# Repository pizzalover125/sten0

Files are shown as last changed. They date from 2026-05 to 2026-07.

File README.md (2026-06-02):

# sten0
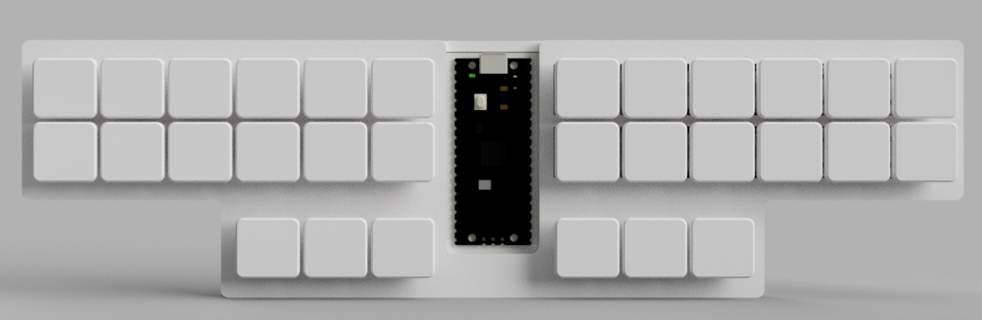
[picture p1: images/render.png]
render


sten0 is a minimalist stenography keyboard. it was meant to defeat the industry standard Uni v4 which is overpriced and unsymmetrical. it uses a 2-layer PCB and KMK firmware that converts to stenography with the industry-standard Plover firmware. 

### what is steno?
traditional stenography keyboards are keyboards used by transcribers in a courtroom to type extremely fast. hobbyists and now companies have created their own versions of steno keyboards. one can easily get 200 wpm using steno, demonstrated in the video here: https://www.youtube.com/watch?v=l8SWkR5y774. 

steno works by pressing multiple keys at once to create "chords" which create words. each key is associated with a specific sound. for example, to write "cat" press "K A T" all at once.

the company, stenokeyboards.com, is the leader of the steno industry with products that are pretty cool, but extremely expensive. worst of all, they are closed source. i wanted to make something better for cheaper.

### PCB + Schematic
I used KiCad 10.0 for the PCB design. The silkscreen art was created using https://www.fontspace.com/ and inputted to KiCad using the built-in Image Convertor tool.

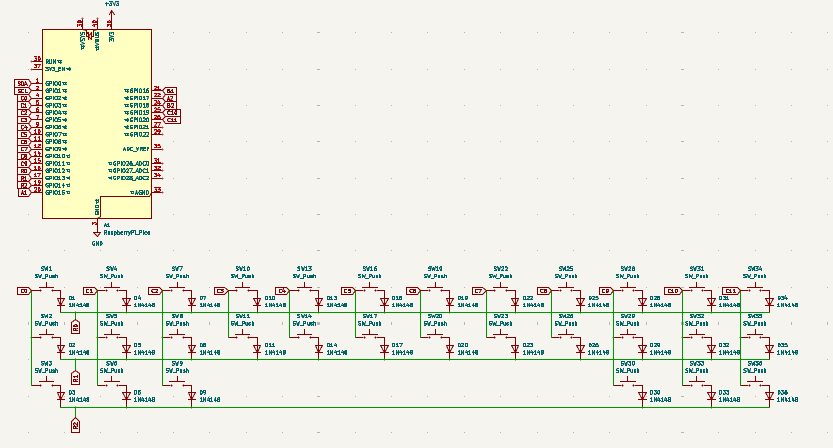
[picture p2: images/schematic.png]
schematic

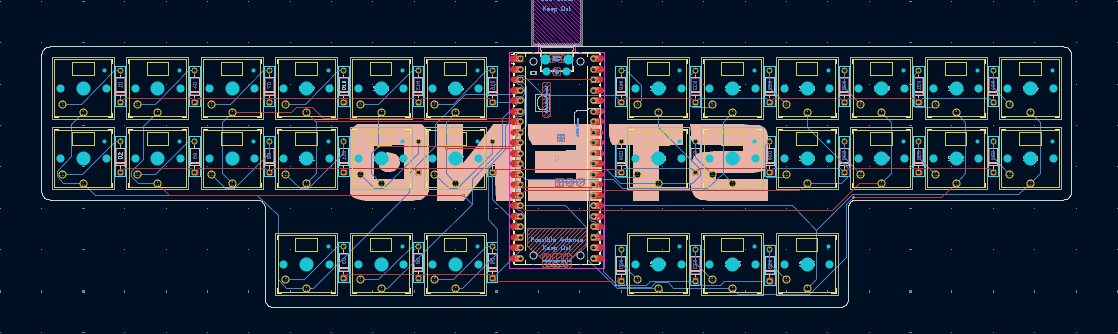
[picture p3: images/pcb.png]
pcb

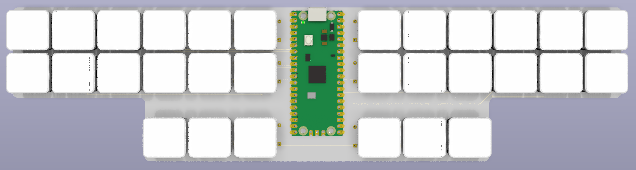
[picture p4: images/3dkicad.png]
3dkicad


### CAD
I used Onshape for the entire CAD. It features a front plate and a back plate. It is only 255.4 mm wide at its widest point, making it printable on a standard Bambu Lab A1 or any Bambu Lab 3d printer. Can be viewed here! https://cad.onshape.com/documents/f60da929d98268854f5791b9/w/b980d7f138533dbdb870e5ad/e/3b5277e683bbd7090a7e44ca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

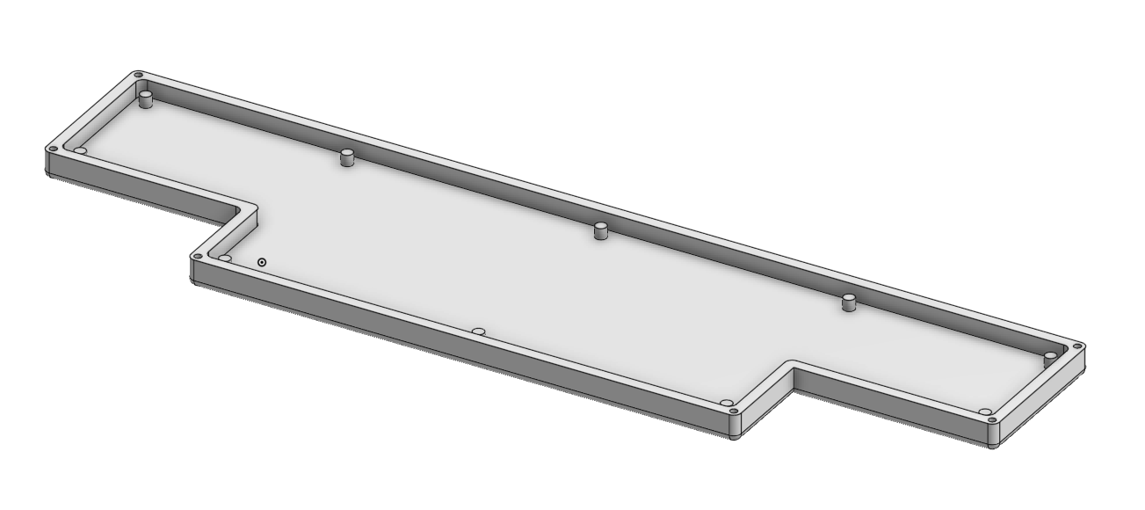
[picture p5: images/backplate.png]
back-plate

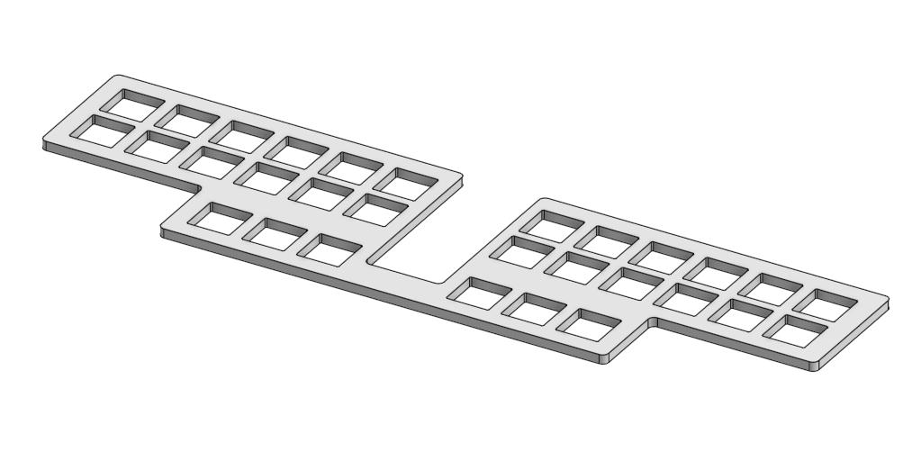
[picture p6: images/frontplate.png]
front-plate

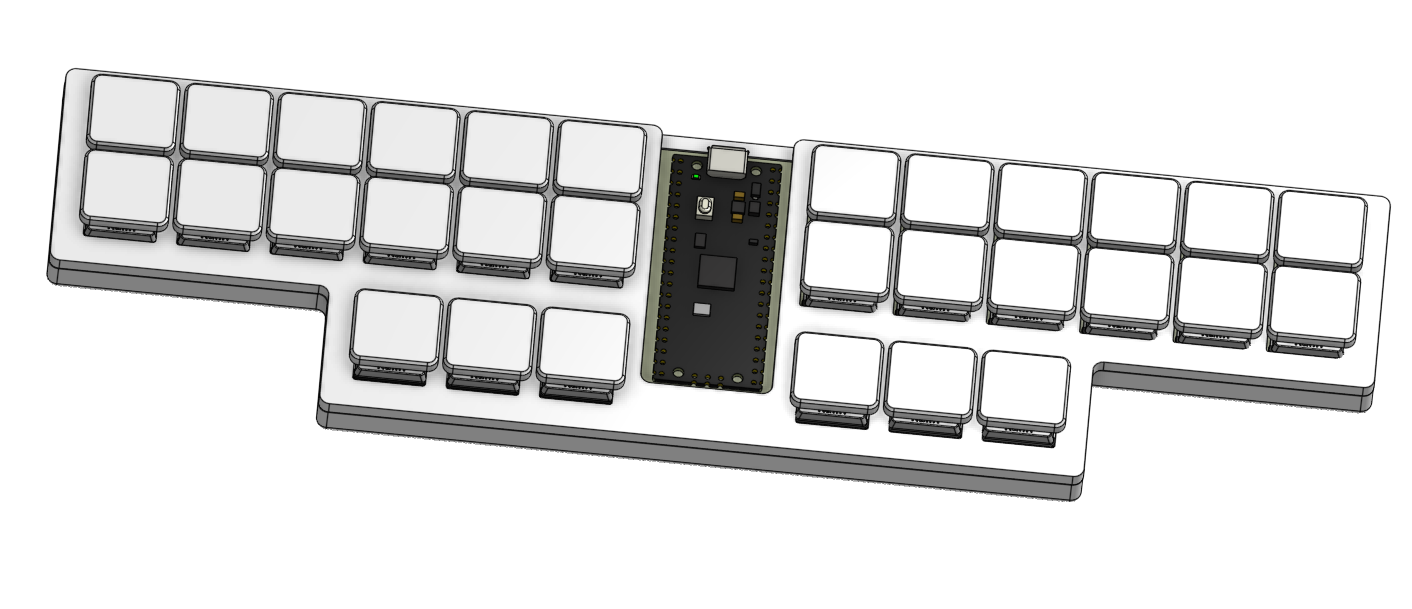
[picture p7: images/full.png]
full


### Firmware
The keyboard uses KMK. There is a standard keyboard matrix that links to standard QWERTY layout which will be converted to Steno layout with Plover firmware.

### Layout
This is the layout for both QWERTY and STENO. The blank keys are macro keys, meaning they can be mapped to anything!



### BOM
A detailed Bill of Materials can be found at https://docs.google.com/spreadsheets/d/1TjUF5DwXCz-duM485mYQtrJNJa8_saizqugbLS9kPO8/edit?gid=0#gid=0!

### Credits
Big thanks to Hack Club for funding the project + providing a LOT of help!

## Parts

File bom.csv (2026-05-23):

Item | Price | Link | Orders |  | Notes
2x RPi Pico Clones | 10.99 | https://www.amazon.com/gp/product/B0DKNKLMXP/ref=ox_sc_act_title_1?smid=A23J2M209QYJMZ&psc=1 | Amazon | 53.00 | The BOM on right is w/o taxes + shipping
70x Choc v1 Brown Switches | 36.89 | https://www.amazon.com/gp/product/B0F9WNSX15/ref=ewc_pr_img_2?smid=A6078EBK4K8X5&th=1 | JLCPCB | 21.08 | The Orders on left is w/ taxes and shipping
100x 1N4148 Diodes | 4.39 | https://www.amazon.com/gp/product/B081JKJM6N/ref=ewc_pr_img_3?smid=AMND9J0IFY6ZR&psc=1 |  |  | Using cheapest shipping on JLC
5x JLC PCB | 2.00 | https://www.amazon.com/gp/product/B081JKJM6N/ref=ewc_pr_img_3?smid=AMND9J0IFY6ZR&psc=1 | Total | 74.08 | Prime shipping on Amazon to make shipping free
4x M2x9 screws | 0.00 | Closet

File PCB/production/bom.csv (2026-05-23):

Designator | Footprint | Quantity | Value | LCSC Part #
A1 | RaspberryPi_Pico_Common_Unspecified | 1 | RaspberryPi_Pico
D1, D10, D11, D13, D14, D16, D17, D19, D2, D20, D22, D23, D25, D26, D28, D29, D3, D30, D31, D32, D33, D34, D35, D36, D4, D5, D6, D7, D8, D9 | D_DO-35_SOD27_P7.62mm_Horizontal | 30 | 1N4148
SW1, SW10, SW11, SW13, SW14, SW16, SW17, SW19, SW2, SW20, SW22, SW23, SW25, SW26, SW28, SW29, SW3, SW30, SW31, SW32, SW33, SW34, SW35, SW36, SW4, SW5, SW6, SW7, SW8, SW9 | SW_PG1350 | 30 | SW_Push

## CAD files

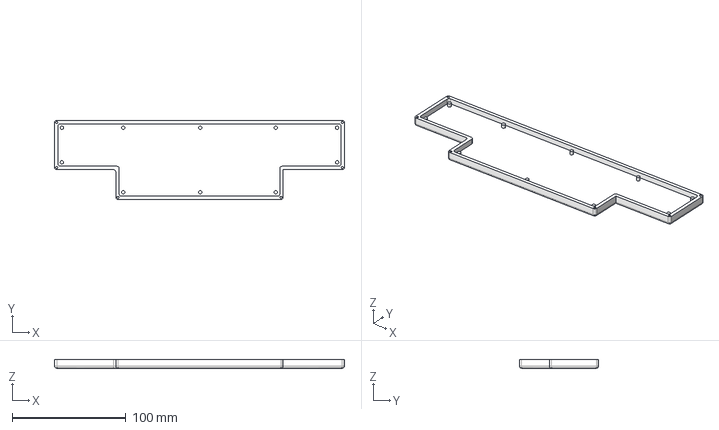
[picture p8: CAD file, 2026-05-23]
CAD/bottom-plate.step
255.4 x 69.8 x 7.50 mm

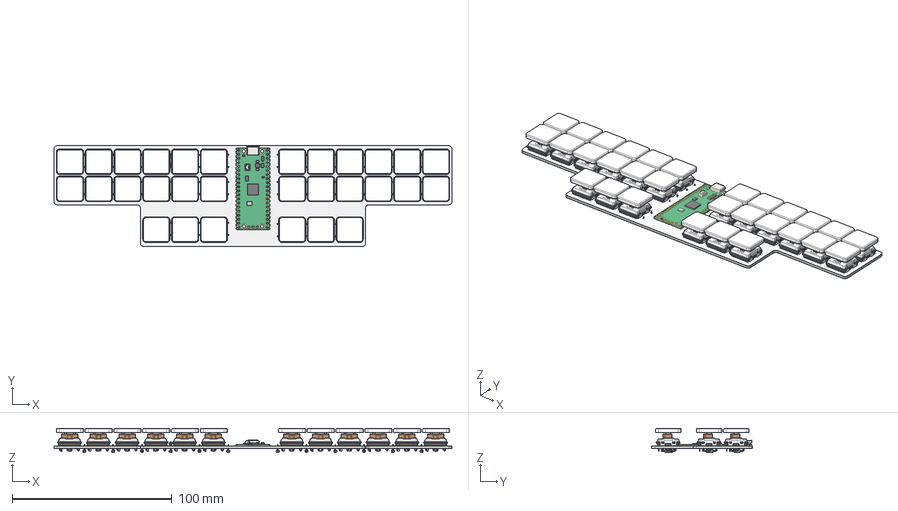
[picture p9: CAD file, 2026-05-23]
PCB/sten0.step
249.0 x 63.0 x 15.3 mm
Document x 240
choctod v7 x 30
RaspberryPi_Pico_Module_KiCad
D_DO-35_SOD27_P7.62mm_Horizontal x 30
sten0_silkscreen x 2
sten0_soldermask x 2
sten0_PCB

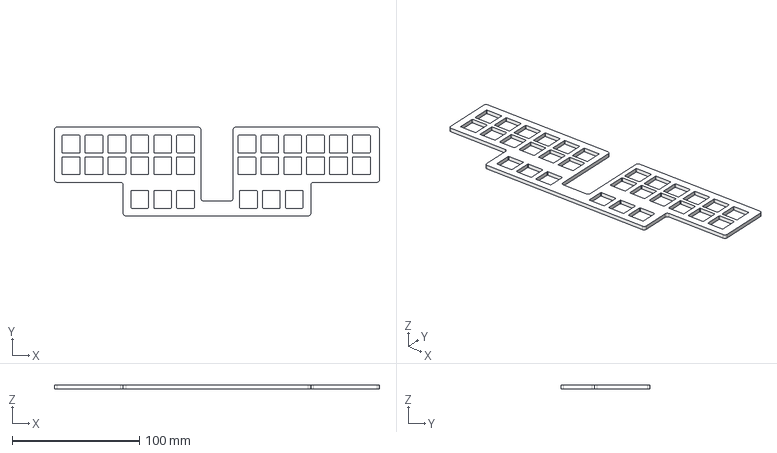
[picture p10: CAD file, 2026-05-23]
CAD/top-plate.step
255.4 x 69.8 x 3.00 mm

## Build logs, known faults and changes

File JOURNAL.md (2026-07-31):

# journal

### 05/12: created idea + plan (20 min)
- created idea after seeing StenoKeyboard's outrageous pricing on https://stenokeyboards.com/products/the-uni-v4
- i've seen videos of people typing at crazy speeds with steno
- what if i made a cheap steno keyboard?
- v1 is going to be basic but i want v2 to be hotswap + RGB
- i could still do hotswap with this thing called "mill-max sockets"
  - they basically plug the PCB holes and make a regular MX footprint become hotswappable
  - require kapton tape
  - ok ill decide this later
- created the thing below
- was originally going to copy the StenoKeyboards layout but Taran told me to make it more unique so I tried doing that 

- ok ill first design w/o LEDs and then add them in v2
- goal of this project is to be ultra-polished in every way possible
  - want some sick renders  

### 5/13: expanded on plan, created initial BOM, figured out firmware (30 min)
- thought about required costs
- decided to make BOM for some reason



- im going to source a lot of parts from Amazon
  - Aliexpress has misdelievered packages
  - lot easier to get parts, replace parts, etc.
- i alr have a bunch of Picos lying around so i'll use one of those
- PCB probably going to be around $20
- realized i need to figure out firmware because it is complex
- found Plover (most popular firmware)
- ok this is a bit weird but basically I can program the keyboard firmware to be like a regular keyboard but Plover will translate the regular keypresses to Steno



- (in this image, I would set the top left key on my PCB to be a "W" on QWERTY which would be translate to the "T" sound on Steno
- ok i basically have firmware figured out!
- ill use a 7*4 matrix layout so I can get the 2 rotary encoders and make them keys
- i tried to draw out the matrix but its hard so ill prob just figure which keys are what after schematic done
- nvm ill use 3x10 cause its easier and i have enough keys and it would be easier to route



### 5/14: redid design + schematic + PCB (140 min)
- before starting the schematic, I wanted to look at other open source Steno boards
- found https://plover.wiki/index.php/DIY_steno_writers
  - they are cool, but none of them have encoders or OLEDs
- omg i just realized my layout is off
- i need another two keys on the left side
- i did not expect almost all steno keyboards to be not aligned?
- thats actually so weird, but ill change my design
- i also need to move the bottom row down by 1 unit
- how did i make all these mistakes wow



- ok that was ez to fix
- time to hop on KiCad
- watching https://www.youtube.com/watch?v=8WXpGTIbxlQ to learn a little bit
- got matrix done
- using this https://pip-assets.raspberrypi.com/categories/610-raspberry-pi-pico/documents/RP-008309-DS-1-Pico-R3-A4-Pinout.pdf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



- schematic done! it was pretty ez
- assigned footprint
  - spent 5 minutes looking for EC11 + cherry mx footrpints but realized they were built in after alex told me
- time to start PCB!
  
  

- finished the keys, encoders, and pico placement; need to do diodes + OLED



- routing time!
- oops forgot to flip the diodes... ill do that rn!
- routed!



- added 3d models for keys
  - took so long for no reason
- added all the other 3d models... these were shorter!



- aight going to call it for a day but great progress today!

### 5/15: part 1: firmware (50 minutes)
- new day; no school!
- wanted to fully figure out the firmware aspect
- found the NKRO layout for https://nolltronics.com/product/picosteno/
  - NKRO is basically a setting you can change on your QWERTY keyboard to actually register all the keys you press at the same time



- basically, ill code firmware w/ regular QMK/KMK and itll be normal keyboard firmware.
- user runs Plover software on their computer
- Plover converts each regular key press to steno
- this way, I can have the OLED + rotary encoders be super easy to code up
- i removed the labels from the front + back silkscreen to make it look better / cleaner
- ill do only firmware today
- i created the keymap:
  
column 1: Q W E R T Y U I Y P [
column 2: A S D F T O J K L ; '
column 3: 2 C V [mute/unmute] [video on/off] N M 8 '

- this looks super simple but it isn't bc i messed up in schematic / placement and some of the keys were swapped around; instead of rerouting, imo fixing it in firmware is better and faster and thats what I did
- wait nvm i messed up; this should be good:

column 1: Q W E R T Y U I Y P 
column 2: A S D F T O J K L ; 
column 3: 2 C V [mute/unmute] [video on/off] N M 8 ' [

- im creating firware w help of Claude (pretty hard to do firmware w/o parts)

### 5/15: part 2: mounting holes (15 minutes)
- adding the mounting holes
- watching https://www.youtube.com/watch?v=TDL3USgDEM0
- realized I only have to press "a" and add M2 hole
- need to position it properly



- i want to make the PCB black (or white i haven't chosen yet)



- looks pretty mid ngl
- okay time to do case
- idk what software to use
- ehhh ill just design a logo today
- time to hop on figma
- nvm my internet went out??????????? why did this happen to me
- uhhhh ig i can't do much so ill end it here for today... unless it comes back

### 5/16: render + polish (120 minutes)
- BRUHHHH MY WHOLE JOURNAL for today GOT DELETED
- basically, I was learning how to Render KiCad
- It was this crazy thing where I had to downgrade KiCAD to 9.0 and then upgrade to 10.0
- I downloaded Blender and Fusion and tried to Render but it wasn't working
- I watched like 5 YT videos trying to figure it out
- So I ultimately decided to have no render
- I added mounting holes + logos



- made back panel



- tried to export from KiCAD as STEP but it doesn't work?
- ok that was a weird bug; i just had to redraw the outline



- pretty basic, ngl
- idk where to add polish
- first im going to add keycaps to make it look better
- nvm no keycaps bc very tedious
- asked for help on Slack: https://hackclub.slack.com/archives/C0B0CADUV3P/p1778990312121819



- what do we think? it looks pretty sick ngl
- idk what else to add for polish
- will look at approved keebs on hardware.hackclub.com
- liked https://github.com/KaiPereira/PR1SM, https://github.com/sudo-apt-install-tap/TaoTeChing, https://github.com/code2344/SplitCodeBoard, https://github.com/meepodeep/ErgoDecks
- ok all of them are pretty standard and i lowk didn't gain much inspiration
- note to self: need to split the keyboard in half to print it
- wait I can just do that in the Bambu Slicer; ok ill just do that
- ok i think plan now is to finalize and then submit
- start w/ BOM



- im genuinely shocked by this
- time to see JLC.. doesn't work?
- ok time to sleep; will see tmrw

### 5/17: polish + BOM (180 minutes)
- started off with a BOM
- wait if I get some more switches I can build 2 keyboards
- ok $6 more for +1 keyboard is not bad
- soooooo that comes down to $67.64 for two keebs or $33.82 for two
  - doesn't include 3d printed case but thats not too bad
- acon told me to look at other keyboard companies
- polish #1: logo on back



- watched https://www.youtube.com/watch?v=YR1xkOp5U1g
- just realized I forgot screws in BOM
- ok apparently i can just use M2x3 without any hex nuts.
- adding to BOM
- ok $80.43 now; still cheaper than an Asterik
- ok going to scroll more on hardware.hackclub.com
- wait b4 that I wanted to round all corners



- wait i don't need mounting holes if tolerance is tight enough
- idk ill still keep them



- rounded literally every corner
- idk what else to make this polished
- ok ive seen so many other keyboards and don't see how mine isn't as polished...
- made PCB shorter
- ok im going to reroute everything to make routing better
- moving two diodes below encoders bc they seem kinda weird
- looks better



- rerouted everything!



- ok imma make a 3d model of the key + keycap
- WHY ALL KEYCAPS ARE SLANTED OMG MGOMOGMOGMOGM
- looks pretty slick NGL




- ill create a rotary encoder w/ cap as well



- time for render!
- not working on render?
- ok its fine 
- added README... ready to submit!

### 5/17: part 2: fixing CAD (15 minutes)
- after I uploaded the thing on Slack, Taran told me I needed some sort of support for the pins
- after a lot of help by him, I made the thing below:



- Taran said it looks good so :yay:
- okay he said to extrude something on bottom
- ill do that later
- ok turns out i also need standoffs for OLED
- will do
- wait i can't extrude a logo or something on bottom bc im splitting it in half

### 5/21: project rejected (1 hr)
- project got rejected... 😭
- got rejected for design which i can understand
- need to make design more cohesive
- no exposed PCB ig
- ok ill make basic face plate then ill spice it up
- nvm ill just create a cool render
- the encoder keeps bugging out; need a fix
- tried like 5 diff models and tweaked a bunch of settings and it worked!






### 5/22: CAD CAD CAD nvm i switched to designing quality PCB (3hr)
- ok time to make a better CAD!
- im thinking i'll do a simpler backplate design with a cool frontplate so its basically a sandwich
- nvm this is too hard
- im switching to exposed PCB style
- time to look for inspo
- watching https://www.youtube.com/watch?v=82yD0RMeEw8
- i came up with the following but it doesn't seem like enough



- OMG IVE BEEN TRYING TO MAKE A CUTOUT FOR USB AND ITS NOT WORKING AHHHHH
- going to redo the PCB layout
- making it low profile now
- removing encoders; bulky and don't look good
- hotswap also cause why not
- nvm no hotswap cause i don't really need it personally



- using only what i need



- routed but just realized its not symetrical 😭
- ok figuring out how to round corners
- figured it out! you just use arcs and move the lines
- acon was right; this feels super nice
- ok time for routing!
- OMG I DID IT WITH 0 VIAS



- im going to create a cool render now
- first i added back silkscreen art



- renders are awesome


Screenshot 2026-05-22 at 8 03 14 PM

- there were these random "K"s next to the diodes, so I removed them
- need to figure out where mounting holes go
- wait i dont need them cause i can just press fit with supports
- created dimensions



- according to my calculations, i need two rectangles; one that is 252x35 and another that is 147x26. 1mm filets



- idk if this will work
- added things in middle:



- added cutout!



- going to render this



- keys may not be able to be pressed

### 5/23: day of shipment (4hr)
- added 1mm more of spacing



- but now i can't 3d print it.
- im thinking to reduce space between Pico and rest



- made it smaller + moved diodes to back
- only 249mm wide
- dimensions: 249x37, 141x26
- 3d modeling time



- w cutout
- and i made a render!



- nvm i need screws apparently
- ahhhhhh have to redesign it again
- wait let me create BOM




- $53 flat is pretty good ngl
- ok back to case design
- watching this https://www.youtube.com/watch?v=cLz7wpwAEoI
- learned a lot about how to make it exposed PCB
- but ill just have a front panel ig



- going to use https://kbplate.ai03.com/ for cutouts
- ok i have no idea on how to do this
- idk what dimensions to use
- i have all of it imported; asked on Slack on how to do it; will continue work after
- actually let me fully prepare the BOM
- lets ring up the PCB cost on JLC
- $21.08... nice!
- let me create BOM.csv
- ok going to upload all PCB files through a Codespace
- added everything except the CAD and CAD images in README
- time to go back to doing CAD! (started 220)
- watching https://www.youtube.com/watch?v=7azQkSu0m_U
- not helpful at all
- manually did it



- cool section view
- ok i made it so the holes are invis
- cutout in middle also
- going to test out micro-usb cable
- it fits!



- voila!
- ok preparing for submission again

### 06/02: updating README (15 min)
- Raygen told me to update it with more details on my exact layout
- sounds like a great idea so ill do it!
- experimenting with https://stenokeyboards.com/products/the-uni-v4 and https://opensteno.org/demo/



- done!
- i have both QWERTY and STENO
- will update README with more info

# BUILD: 8 hours

## Jun 25: 5 hours

### soldering
- Recieved all the parts today
- Was NOT expecting to get the PCBs this quick
- But very excited nonetheless
- Got straight to building
- Recorded my soldering cause why not
- Started with diodes
- Diodes were pretty simple, just pretty sharp
- switches slotted right in; no frills
- Pico was pretty hard to solder
- I moved Pico to a breadboard to solder headers
- there were bridges, but easy to remove
- but when i put them on the board, something went wrong
- THERE WERE SO MANY SOLDER BRIDGES
- I thought I could just remove the bridges like normal... right?
- NOPE! They just wouldn't come off
- I WAS SO MAD
- I had to switch the soldering iron tip a couple of times
- and eventually, they worked!

### firmware
- when I plugged it in; nothing lit up
- i was devestated; did I mess up something?
- did I fry the pico?
- i frantically connected and reconnected the cable
- nothing happened
- i remembered... this pico doesn't like my USB-C port and needs a USB-A cable
- the pico lit up!
- i was really happy but also nervous about the firmware not working
- i uploaded the firmware
- and it didn't work
- oh wait i just needed to add the missing folder
- i added the kmk folder
- still nothing
- seems like my firmware was broken
- i used the getting started guide by KMK
- one key worked!
- it was time to figure out the other keys
- i manually added the other GPIO pins and the keys
- it was a tedious process, but i eventually got all but 3 working properly
- these three were confusing cause they just didn't register
- i tried changing some values aruond but nothing seemed to work
- after a long time, i realized i had entered 20, 21 instead of 19, 20
- when i made that super simple fix, it worked!
- i was actually so thrilled
- this was my first built hardware project other than my hackpad
- i was also happy because i don't need to worry about ordering another PCB cause this one works
- I have a 3D printer so I can tweak the design as needed

### 3d print
- I wasn't sure if my white filament was enough
- so i switched it to black
- but it didn't end up working after multiple failed prints
- so im moving back to black
- ok it printed
- but it doesn't fit
- need to tweak the model
- i printed a keycap
- it fits!
- didn't like the design tho
- going to use this simple one: https://www.printables.com/model/700878-simple-choc-v1-flat-keycaps/files



- printed! looks super clean
- redesigning the thing now
- wait nvm i can just cutout the pins
- it fits!
- WHAAAT THE KEEB DOESN'T WORK ANYMORE
- NOOOOOOOOOOO
- fixed it!
- it was a messy solder connectionm
- shoutout to @Naytik on slack for the help

### 6/26: 2 hours
- last night, i printed the top plate that I CADded
- to add it, i needed to remove the keycaps
- unfortunately, the keycaps got stuck
- so i have to replace those switches
- asked to buy solder wick
- tried a bunch of things before asking like using glue or the leg of a diode
- while the wick is being shipped by AMZN, i'll design the top plate




- looks pretty clean!



- it doesn't work
- asked in Slack
- ok apparently i had to wash the bed
- did that!
- reprinted
- printed perfectly!
- however, it its too flimsy and the screws dont fit
- reprinting the model with bigger screw holes and more thickness
- did it!
- for 30 minutes, i tried screwing it in with my screws from AMZN
- but then i realized i got the wrong type of screw
- i needed self tapping
- i went to lowes and got some
- it worked awesome! except it broke the 3d print



- ok remodeled it
- voila!



### 6/27: 30 min
- i reprinted the top half to work
- it fit perfectly!
- i thought, wow, I'm going to ship this today!
- i printed a keycap
- it fit
- i printed more of that keycap, thinking the end was near
- nope! it didn't fit
- i literally tried like 5 other online models and NONE OF THEM worked
- looked on AMZN, but those while not work with my spacing
- looks like ill need to buy from an actual keyboard website
- i might design my own keycap to work
- but wow this is frustating

### 7/01 (30 min)
- found a keycap model that works!!! (after going through another 2)
- LETS GO
- IM SO HAPPY RN ITS UNBELIEVABLE
- THEY FIT PERFECTLY

View recent photos 2

- im so so happy

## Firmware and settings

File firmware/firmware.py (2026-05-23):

import board
from kmk.kmk_keyboard import KMKKeyboard
from kmk.keys import KC
from kmk.scanners import DiodeOrientation
from kmk.hid import HIDModes

keyboard = KMKKeyboard()

keyboard.col_pins = (
    board.GP2, board.GP3, board.GP4, board.GP5, board.GP6, board.GP7,
    board.GP8, board.GP9, board.GP10, board.GP11, board.GP20, board.GP21,
)
keyboard.row_pins = (board.GP12, board.GP13, board.GP14)
keyboard.diode_orientation = DiodeOrientation.COL2ROW

keyboard.keymap = [
    [
        KC.VOLD, KC.VOLU, KC.N1, KC.N2, KC.N3,   KC.N4,
        KC.N5,   KC.N6,   KC.N7, KC.N8, KC.N9,   KC.N0,

        KC.Q, KC.W, KC.E, KC.R, KC.T, KC.C,
        KC.V, KC.U, KC.I, KC.O, KC.P, KC.LBRC,

        KC.A, KC.S, KC.D, KC.F, KC.G,    KC.N,
        KC.M, KC.J, KC.K, KC.L, KC.SCLN, KC.QUOT,
    ],
]

if __name__ == '__main__':
    keyboard.go(hid_type=HIDModes.NKRO)

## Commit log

2026-05-13 Add description for sten0 steno board
    Added a brief description of the sten0 steno board.
2026-05-15 Redesign Steno keyboard layout and complete PCB
    Redesigned the layout and completed schematic and PCB for the Steno keyboard. Added 3D models and routed the design.
2026-05-15 Initialize firmware for keyboard with encoders and display
2026-05-15 Initialize keyboard with matrix and encoder setup
2026-05-15 Document progress on PCB design and challenges
    Added notes about mounting holes and PCB design progress, including software considerations and internet issues.
2026-05-17 Update journal with KiCad rendering progress
    Documented progress on KiCad rendering and design updates, including issues faced and solutions implemented.
2026-05-17 Update JOURNAL.md with keyboard design notes
    Added additional notes and images related to keyboard design and BOM adjustments.
2026-05-17 Update JOURNAL.md with polishing details and time
    Updated time spent on polishing and BOM from 60 to 140 minutes. Added details about PCB routing changes and 3D modeling of key and keycap.
2026-05-17 added evrything
    [backplate.step, bom.csv, designators.csv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]
2026-05-17 added images
    Added images and additional details about PCB, CAD, and firmware.
2026-05-17 Add explanation of steno keyboards and project motivation
    Added a section explaining traditional stenography keyboards and the motivation behind creating a budget-friendly steno board.
2026-05-23 added stuff
    [backplate.step, bom.csv, designators.csv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]
2026-05-23 finished v2!
    [bom.csv, bottom-plate.step, top-plate.step]
